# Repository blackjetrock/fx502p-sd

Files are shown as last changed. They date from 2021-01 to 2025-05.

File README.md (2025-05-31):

# Adapter for FX-502p Calculator Interface

Adapter that allows calculator to access and SD card and GPIOs on an STM32. Allows I2c and thermal printer printouts.



 The sketch accepts commands from the 502p and stores the data
 words on the SD card under a filename specified on the 502p. This
 is a three digit number. When loading back the data words are sent
 as they were received.

 The files are FILEtnnn.DAT

    where nnn is the 3 digit file number
    and t is the type of the file:
         M for memories
         P for programs

 We leave the data line as an open drain
 output, even when we want to use it as an input. This saves the
 cycles needed to call pinMode(). Time is short when processing
 the commands from the 502p so all of the processing is done in
 interrupt routines using nested switch FSMs

 The header has been cut down to the minimum that works (50 words)
 and there's no delay when sending data words to or from the 502p.
 This means loading and saving is faster than using the FA-1

 There is code in this sketch to set and read the time and date. This
 uses a DS3231 RTC attached to the PC7 and PC6 GPIO lines on the gpio
 connector J7. On the module I used, GND and VCC lined up with GND and 3V3 on J7 
 so the code uses the GPIO lines that line up with SDA and SCL and create 
 an I2C bus on those pins.

Commands
========

The FX502P communicates with the gadget using the INV SAVE INV EXE keystroke. This saves the 
current display value to the tape interface. The commands are coded in numbers, so to issue a command 
enter the number on the calculator and then press INV SAVE INV EXE
So, for example, to display the help text page onm the OLED display you need to enter 1.0E40 and then
INV SAVE INV EXE. The help text should then be shown on the OLED display.

1.0 E40

This command displays help text on the OLED screen. Press the decimal point key to move
to the next page of help text.

1.1 E40

Display status page

1.2 E40
Display the graphics page.
Pixels can be set on this page using the graphics commands

1.3 E40
Display memory page.
This page shows memories that have been sent using an INV SAVE EXE in MODE 1

1.4 E40
Display text page. text can be placed on this page with the text commands.

1.5 E40
Display token page
This page display program tokens sent using INV SAVE EXE in MODE 3
Page using the decimal point key.

1.6 E40
This page displays the current date and time. An RTC module must be attached using I2C.

1.70 E40
Turns printing off

1.71 E40
Turns printing on

A.BC E47

This sets the current filename for programs to PABC.DAT. This is needed as even though the file number
is entered on the calculator when savng and loading that number does not go over the interface when loading.

A.BC E48

This set sthe current filename to MABC for memory saving and loading.

A.BCD E49

This sets the filename bank to ABCD. The filename banks are a way to have more than 1000 programs or memories stored on an SD card. 

Real Time Clock Commands
------------------------
This requires a DS3231 I2C real time clock module to hold the time and date. It needs to be attached to the I2C

1.0 E42 : Read date

After this is received, the date can be read using an
 
	 inv LOAD inv EXE
	  or
	 inv LOAD EXE

The date is in either the X register or the F memory
respectively.
	 
2.0 E42 : Read time

After this is received, the time can be read using an
 
	 inv LOAD inv EXE
	  or
	 inv LOAD EXE
	
respectively.

2.yymmdd E42 : Set date

3.hhmmss E42 : Set time

Text Display Commands
---------------------

Put text on the display

1.xxyy E41     
  
  Set cursor to (x,y)
  
2.aabbccdd E41   
  
3.aabbccdd E41   
  
  Print text on printer, aa etc are ascii codes

Graphics Display Commands
-------------------------

Sample Programs
---------------

The directory 

Sample_FX502P_Programs

holds some example programs.

- P998  Draws random dots on the OLED display
- IMAG2680

- P999  Draws a sine wave on the OLED display
IMAG2677

Printer
-------

The gadget can drive a simple thermal printer of the type used for receipt printing. An external PSU is required for printing due to the current requirements of the printer. Check the printer details for the curren tit uses, if it doesn't say, assume a 2A or higher PSU is needed, these printers take a lot of current. 
The attachment is on J3. there's an (unmarked) GND connection which should be attached to the PSU for the printer. The TX line sends data to the printer when enabled in the gadget.
When conneted and enabled, saving a program or memories results in the data being printed out, in ASCII.

This is the printer attached to the gadget. The black lead is GND:
IMAG2673

This is the rear of the printer showing the connections:
IMAG2676

The details of the printer PSU I used. This was just one I had lying about, I made a socket connection for it.
IMAG2674

This is th eprinter I used, with some sample output.
IMAG2675

This is the output when printing programs (ignore the memory line at the top, that is what is printed if INV SAVE INV EXE is used in MODE1):
IMAG2679

And this is the printout of memories:
IMAG2678

#
# Note:
# Although the FX-602P uses a similar command set it doesn't yet work with this adapter. It should be possible to make it work though.
# The FX-702p uses the same command set but operates at 5V so it also doesn't work with this adapter without some form of level shifter.

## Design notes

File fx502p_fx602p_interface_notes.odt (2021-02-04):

Casio fx502p fx602p Interface

The Expansion Port

### Pin functions

Expansion Port Pin | Symbol | Function
1 | CE | Chip enable output, active high
2 | GND | Ground (positive supply voltage rail)
3 | D8 | Data input/output (bi-directional)
4 | CONT | -3V when operational, 0V when stand-by
5 | OP | Selects the Command Register (OP=0) or Data Register (OP=1)
6 | VDD1 | -3V (negative supply voltage rail)
7 | SP | Clock output

Additional commands used by the FX-602P

Code Function Description

001100 Wait This command suspends the data transfer for a while when reading from the tape. The calculator issues it after loading of the file header, then reads a single data bit. The meaning of this value is unknown to me (the interface always returns 1).

110100 Counter This command defines the frequency of the music tone. It expects an 8-bit value (the least significant bit first).

frequency = 32768Hz/value

001110 Play the sound After sending this command, signal of frequency specified by the Counter command appears on the MIC output.

111110 Stop the sound This command terminates generating the music tone.

111100 Close Apart from closing the communication channel, this command has an additional function.After sending it, the calculator can read a single data bit which returns the Cal/Music switch state (Cal=0, Music=1). Otherwise, this switch doesn't seem to influence the function of the controller.

Example of playing music

1. OP=0 111100 ;test the Cal/Music switch

OP=1 1 ;returned value=1,

;means the switch in the "Music" position

2. OP=0 111110 ;stop the sound

3. OP=0 110100 ;preset the counter according to the note pitch

OP=1 01001010 ;value=0x52 (frequency=400Hz)

4. OP=0 001110 ;play the sound

5. delay depending on the tempo

6. goto 1, until all notes played

7. OP=0 000000 ;reset

8. OP=0 111110 ;stop the sound

fx602p power on sequence (gadget)

+++Buffer Count:11

*0 19 (6 bits)

*1 03 (6 bits)

*2 00 (1 bits)

*3 1B (6 bits)

*4 03 (6 bits)

*5 00 (1 bits)

*6 19 (6 bits)

*7 03 (6 bits)

*8 00 (1 bits)

*9 00 (6 bits)

*10 3E (6 bits)

fx602p inv save EXE sequence:

*11 19 (6 bits)

*12 07 (6 bits)

*13 07 (6 bits)

*14 0E (7 bits)

*15 28 (6 bits)

*16 04 (6 bits)

*17 00 (1 bits)

*18 04 (6 bits)

*19 00 (1 bits)

*20 04 (6 bits)

*21 00 (1 bits)

*22 04 (6 bits)

*23 00 (1 bits)

*24 04 (6 bits)

*25 00 (1 bits)

*26 04 (6 bits)

*27 00 (1 bits)

*28 04 (6 bits)

*29 00 (1 bits)

*30 04 (6 bits)

*31 00 (1 bits)

*32 04 (6 bits)

*33 00 (1 bits)

*34 04 (6 bits)

*35 00 (1 bits)

*36 04 (6 bits)

*37 00 (1 bits)

*38 04 (6 bits)

*39 00 (1 bits)

*40 04 (6 bits)

*41 00 (1 bits)

*42 04 (6 bits)

*43 00 (1 bits)

*44 04 (6 bits)

*45 00 (1 bits)

*46 04 (6 bits)

*47 00 (1 bits)

*48 00 (6 bits)

*49 00 (1 bits)

*50 04 (6 bits)

*51 00 (1 bits)

*52 04 (6 bits)

*53 00 (1 bits)

*54 04 (6 bits)

*55 00 (1 bits)

*56 04 (6 bits)

*57 00 (1 bits)

*58 04 (6 bits)

*59 00 (1 bits)

*60 0C (6 bits)

*61 00 (1 bits)

*62 04 (6 bits)

*63 00 (1 bits)

*64 04 (6 bits)

*65 00 (1 bits)

*66 04 (6 bits)

*67 00 (1 bits)

*68 0C (6 bits)

*69 00 (1 bits)

*70 04 (6 bits)

*71 00 (1 bits)

*72 04 (6 bits)

*73 00 (1 bits)

*74 04 (6 bits)

*75 00 (1 bits)

*76 0C (6 bits)

*77 00 (1 bits)

*78 04 (6 bits)

*79 00 (1 bits)

*80 04 (6 bits)

*81 00 (1 bits)

*82 04 (6 bits)

*83 00 (1 bits)

*84 0C (6 bits)

*85 00 (1 bits)

*86 04 (6 bits)

*87 00 (1 bits)

*88 04 (6 bits)

*89 00 (1 bits)

*90 04 (6 bits)

*91 00 (1 bits)

*92 0C (6 bits)

*93 00 (1 bits)

*94 04 (6 bits)

*95 00 (1 bits)

*96 04 (6 bits)

*97 00 (1 bits)

*98 04 (6 bits)

*99 00 (1 bits)

*100 0C (6 bits)

*101 00 (1 bits)

*102 04 (6 bits)

*103 00 (1 bits)

*104 04 (6 bits)

*105 00 (1 bits)

*106 04 (6 bits)

*107 00 (1 bits)

*108 0C (6 bits)

*109 00 (1 bits)

*110 04 (6 bits)

fx502p Gadget Traces

Power On:

First column is packet number

*6358 00 (6 bits) ;

*6359 3E (6 bits) ; Stop command

inv SAVE EXE:

*6364 0C (6 bits)

*6365 00 (1 bits)

*6366 28 (6 bits)

*6367 08 (7 bits)

*6368 08 (7 bits)

*6369 08 (7 bits)

*6370 08 (7 bits)

*6371 08 (7 bits)

08 repeats indefinitely.

FX-502P Opcodes

Modifying a program to try out different invalid codes:

0x3B Displays as F5. xD

0x2B E on load

0x2C Seems to behave like HLT

0x2D E on load

0x2E E on load

0x2F Seems to behave like HLT

0x6A E on load

0x9B inv hyp

0xEA FF-F5-CC (inv hyp ABS) inv hyp sin function

0xEB E on load

0xEC FF-F5-C1 (inv hyp FRAC) inv hyp sin function

0xF5 E on load

0xFB FF-PP NOP

0xFC E on load

0xFD Displays as E3 (+) in mode 2 listing, but when executes shows the step in mode 2 format on LCD then locks up the calculator. Power off is only way to recover.

0xFE Displays as 0C Not sure what it does.

0xFF E on load

You can have multiple programs with the same Pn number. Only the last one seems to be loaded. Also can have different invalid Pn numbers and load doesn’t fail, but code isn’t there.

You can easily renumber programs by altering Pn numbers

Altering the first two bytes of a saved program or data file:

23 01 F0123

23 10 F1023 while loading but won’t load

23 20 F2023

23 30 F3123

23 40 F4023

23 50 E on load

23 60 E on load

23 70 F7023

23 80 F8023

23 90 E on load

23 A0 E on load

23 B0 FP023 (program file)

23 C0 E on load

23 D0 FE023

23 F0 FP023 (Memory load)

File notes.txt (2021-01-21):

Extend inv save setting of file numbers beyond 999.

x.yz E 47    Program file number xyz
x.yz E 48    Data file number xyz

This can be extended to

abcdefxyz E 49 sets extended file number but still puts 3 digit number in data.

Programs can't be chained but the external processor could execute it.

Display can be used to decode memories and programs saved and display them
Use display as a larger screen for results.

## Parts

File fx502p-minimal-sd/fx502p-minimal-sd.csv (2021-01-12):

Id | Designator | Package | Quantity | Designation | Supplier and ref
1 | R22 | R_0805_2012Metric_Pad1.15x1.40mm_HandSolder | 1 | 10k
2 | D1 | D_SOD-323_HandSoldering | 1 | D
3 | J7 | PinHeader_1x10_P2.54mm_Vertical | 1 | Conn_01x10_Female
4 | R11,R10 | R_0805_2012Metric | 2 | 10k
5 | JP4,JP3,JP2,JP1 | SolderJumper-2_P1.3mm_Open_RoundedPad1.0x1.5mm | 4 | Jumper
6 | J6,J3 | PinHeader_1x03_P2.54mm_Vertical | 2 | Conn_01x03_Female
7 | X2 | Crystal_SMD_HC49-SD_HandSoldering | 1 | 8MHz
8 | U3 | SOT-223-3_TabPin2 | 1 | AMS1117-3.3
9 | U1 | LQFP-64_10x10mm_P0.5mm | 1 | STM32F103RGTx
10 | SW2 | SMD_BUTTON | 1 | Switch_SW_SPST
11 | R23 | R_0805_2012Metric_Pad1.15x1.40mm_HandSolder | 1 | 1M
12 | R21,R9,R8 | R_0805_2012Metric | 3 | 4k7
13 | R20,R18 | R_0805_2012Metric | 2 | 20R
14 | R7 | R_0805_2012Metric | 1 | 390R
15 | R6,R5,R4,R3,R2,R1 | R_0805_2012Metric | 6 | R_Small
16 | P1 | expansion_fx502p | 1 | Expansion
17 | J10 | PinHeader_1x04_P2.54mm_Vertical | 1 | Conn_01x04
18 | J9 | PinHeader_1x05_P2.54mm_Vertical | 1 | Conn_01x05
19 | J5,J4 | PinHeader_1x04_P2.54mm_Vertical | 2 | Conn_01x04_Male
20 | J2,J1 | PinHeader_1x02_P2.54mm_Vertical | 2 | Conn_01x02_Male
21 | C36,C35,C34,C33,C32,C31,C30,C29,C28,C27,C26,C25,C19 | C_0805_2012Metric_Pad1.15x1.40mm_HandSolder | 13 | 100nF
22 | C24,C22,C20 | C_0805_2012Metric_Pad1.15x1.40mm_HandSolder | 3 | 1uF
23 | C23,C21 | C_0805_2012Metric_Pad1.15x1.40mm_HandSolder | 2 | 10pF
24 | A1 | SD_Card_Module | 1 | SD_Card_Module_catalex

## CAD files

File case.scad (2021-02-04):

// Case for PCB

case_th = 13/2;
pcb_th = 5;

module PCB()
{
  cube([70.2, 65.5, pcb_th], center = true);
  translate([-65.5/2-15/2+15+20, -70.2/2-2/2+0.1, 0])
    cube([15, 2, pcb_th], center=true);
}


module case()
{
    cube([80, 100, case_th], center=true);
}

module calculator()
{
    cube([76.0, 50.0, 2.0], center=true);
    cube([70.7, 50, 9.5], center=true);
}

module case2 ()
{
difference()
{
  translate([0, 0, 0.5])
  case();
  translate([0,0+7.5, case_th/2-1.6/2+0.1-0.8+(5-1.6)/2])
    PCB();
    translate([0, -50, 9.5/2+5/2-9.5/2-1.6/2])
    calculator();
}
}

difference()
{
case2();
    translate([0, 50,0])
    cube([100,100,100], center=true);
}

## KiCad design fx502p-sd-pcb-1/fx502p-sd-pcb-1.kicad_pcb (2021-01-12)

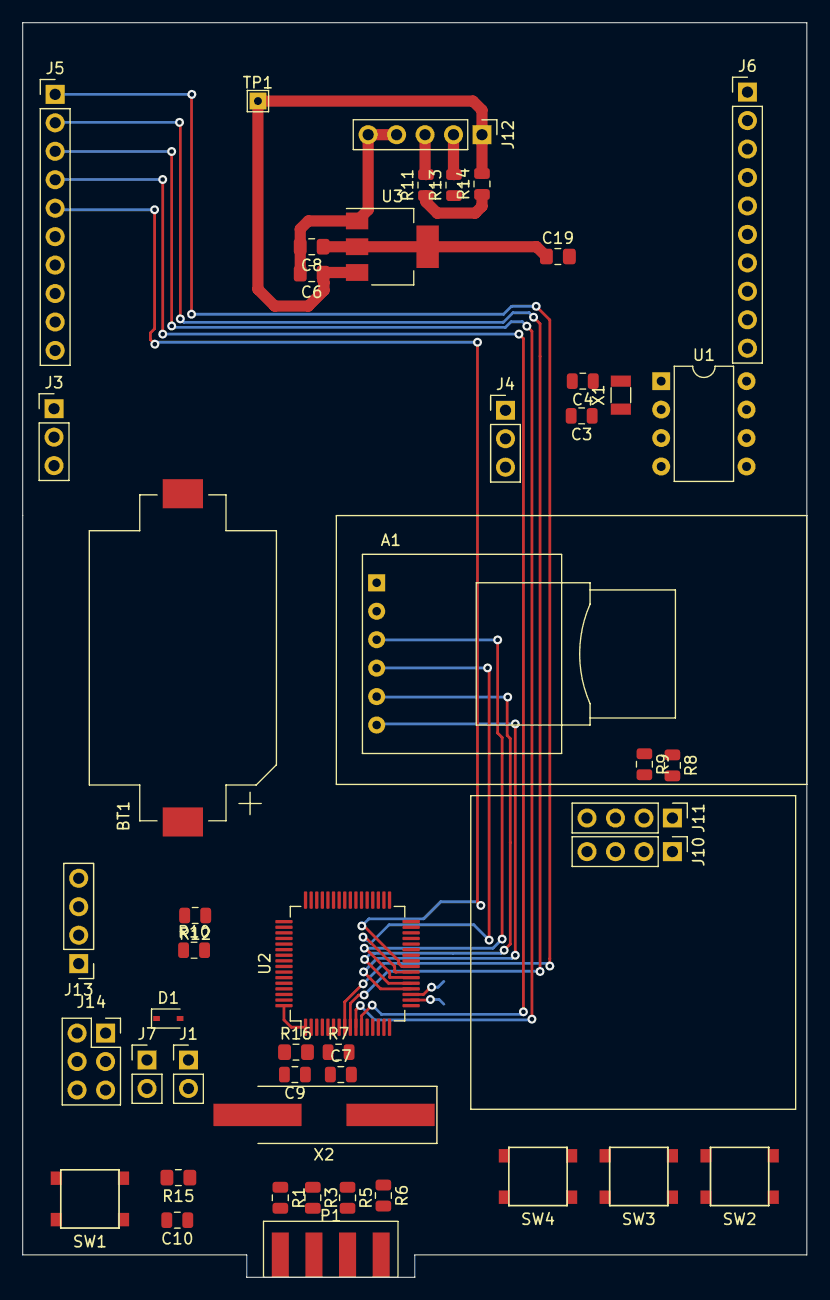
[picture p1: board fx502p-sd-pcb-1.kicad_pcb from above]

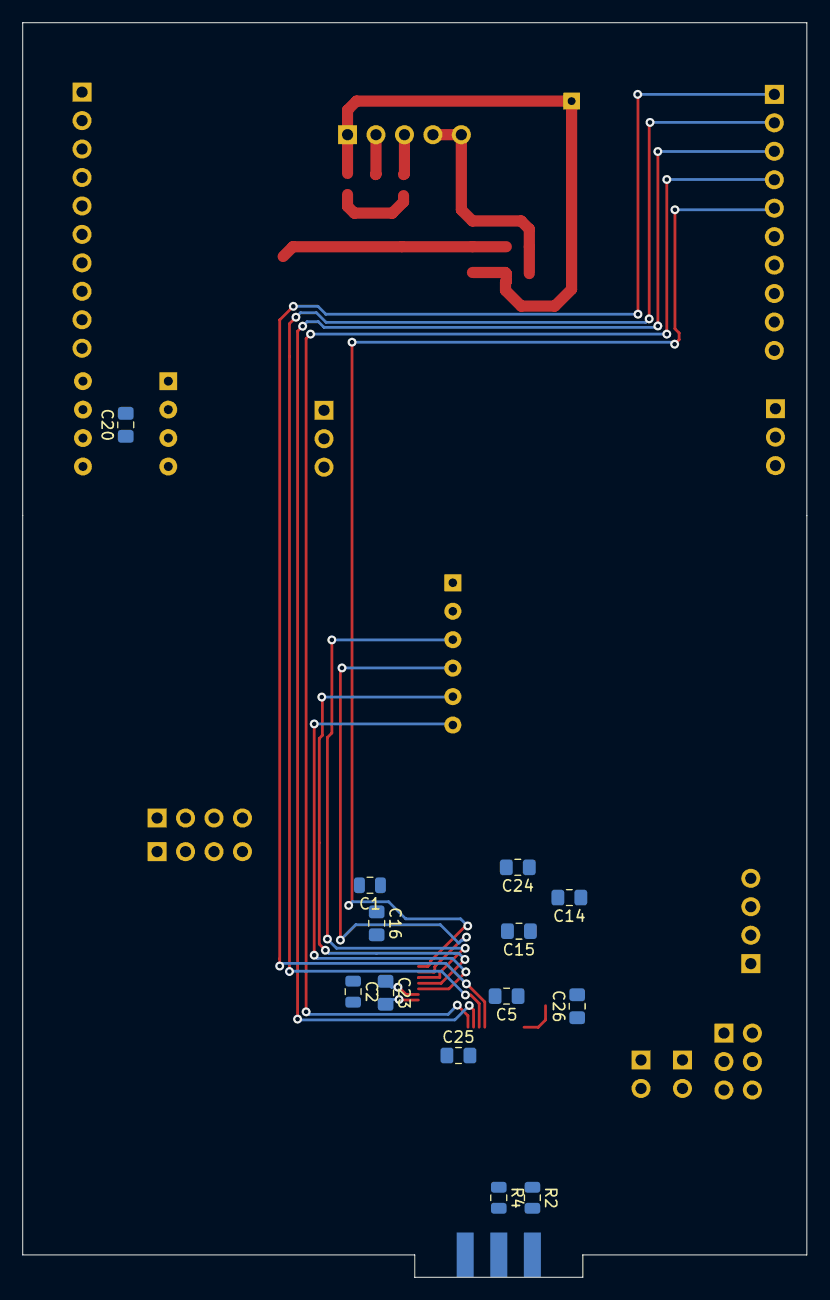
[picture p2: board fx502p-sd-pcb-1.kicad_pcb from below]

Board: 2 copper layers, 70.0 x 112.0 mm, 60 parts (13 on the bottom side), 62 nets.

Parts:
A1: SD_Card_Module_catalex; SD_Card_Module
BT1: Battery_Cell; BatteryHolder_Keystone_1060_1x2032
C1, C2: 100nF; C_0805_2012Metric
C3, C4, C7, C9: 10pF; C_0805_2012Metric
C5, C14, C15, C16, C19, C20, C23, C24, C25, C26: 100nF; C_0805_2012Metric_Pad1.15x1.40mm_HandSolder
C6, C8: 1uF; C_0805_2012Metric_Pad1.15x1.40mm_HandSolder
C10: 1uF; C_0805_2012Metric
D1: D; D_SOD-323
J1, J7: Conn_01x02_Male; PinHeader_1x02_P2.54mm_Vertical
J3: Conn_01x03_Female; PinHeader_1x03_P2.54mm_Vertical
J4: Conn_01x03_Male; PinHeader_1x03_P2.54mm_Vertical
J5, J6: Conn_01x10_Male; PinHeader_1x10_P2.54mm_Vertical
J10, J11: Conn_01x04_Male; PinHeader_1x04_P2.54mm_Vertical
J12: Conn_01x05; PinHeader_1x05_P2.54mm_Vertical
J13: Conn_01x04; PinHeader_1x04_P2.54mm_Vertical
J14: Conn_02x03_Odd_Even; PinSocket_2x03_P2.54mm_Vertical
P1: Expansion; expansion_fx502p
R1, R2, R3, R4, R5, R6, R8, R9: R_Small; R_0805_2012Metric
R7: 390R; R_0805_2012Metric
R10, R12: 10k; R_0805_2012Metric
R11, R13: 20R; R_0805_2012Metric
R14: 4k7; R_0805_2012Metric
R15: 10k; R_0805_2012Metric_Pad1.15x1.40mm_HandSolder
R16: 1M; R_0805_2012Metric_Pad1.15x1.40mm_HandSolder
SW1, SW2, SW3, SW4: Switch_SW_SPST; SMD_BUTTON
TP1: TestPoint; TestPoint_THTPad_1.5x1.5mm_Drill0.7mm
U1: MCP7940N-xSN; DIP-8_W7.62mm
U2: STM32F103RGTx; LQFP-64_10x10mm_P0.5mm
U3: AMS1117-3.3; SOT-223-3_TabPin2
X1: 32.768kHz; Crystal_SMD_3215-2Pin_3.2x1.5mm
X2: 8MHz; Crystal_SMD_HC49-SD_HandSoldering

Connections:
+3V3: C2.1, C5.1, C8.1, C14.1, C15.1, C16.1, C19.1, C20.1, C23.1, C24.1, C25.1, C26.1, J1.1, J4.1, J5.9, J6.9, J10.3, J11.4, J13.1, J14.1, J14.2, R8.1, R9.1, R15.1, U1.8, U2.1, U2.13, U2.19, U2.32, U2.48, U2.64, U3.2
+5V: A1.2, C6.1, J12.1, R14.2, TP1.1, U3.3
BOOT0: R10.2, U2.60
BOOT1: R12.1, U2.28
CALC_CE: R1.1, U2.34
CALC_CONT: R4.1, U2.36
CALC_D3: R3.1, U2.55
CALC_GND: A1.1, BT1.2, C1.2, C2.2, C3.2, C4.2, C5.2, C6.2, C7.2, C8.2, C9.2, C10.2, C14.2, C15.2, C16.2, C19.2, C20.2, C23.2, C24.2, C25.2, C26.2, J3.1, J5.10, J6.10, J10.4, J11.3, J12.4, J12.5, J13.4, J14.5, J14.6, P1.6, SW1.2, SW2.2, SW3.2, SW4.2, U1.4, U2.12, U2.18, U2.31, U2.47, U2.63, U3.1
CALC_OP: R5.1, U2.56
CALC_SP: R6.1, U2.33
CALC_VCC: D1.1, J7.1, U2.35
NRST: C10.1, R15.2, SW1.1, U2.7
unnamed: BT1.1, J4.3
unnamed: C1.1, J4.2, U1.3
unnamed: C3.1, U1.2, X1.2
unnamed: C4.1, U1.1, X1.1
unnamed: D1.2, J1.2
unnamed: J5.1, U2.8
unnamed: J5.2, U2.9
unnamed: J5.3, U2.10
unnamed: J5.4, U2.11
unnamed: J5.5, U2.24
unnamed: J5.6, U2.25
unnamed: J5.7, U2.37
unnamed: J5.8, U2.38
unnamed: J6.1, U2.39
unnamed: J6.2, U2.40
unnamed: J6.3, U2.51
unnamed: J6.4, U2.52
unnamed: J6.5, U2.53
unnamed: J6.6, U2.2
unnamed: J6.7, U2.3
unnamed: J6.8, U2.4
unnamed: J7.2, R2.1
unnamed: J12.2, R13.2
unnamed: J12.3, R11.2
unnamed: J14.3, R10.1
unnamed: J14.4, R12.2
unnamed: P1.1, R1.2
unnamed: P1.2, R2.2
unnamed: P1.3, R3.2
unnamed: P1.4, R4.2
unnamed: P1.5, R5.2
unnamed: P1.7, R6.2
unnamed: R7.2, U2.6
unnamed: SW2.1, U2.14
unnamed: SW3.1, U2.15
unnamed: SW4.1, U2.16
OSCI: C7.1, R16.2, U2.5, X2.1
OSCO: C9.1, R7.1, R16.1, X2.2
PA11: R13.1, U2.44
PA12: R11.1, R14.1, U2.45
RX: J3.2, U2.43
SCL: J10.2, J11.2, R9.2, U1.6, U2.29
SDA: J10.1, J11.1, R8.2, U1.5, U2.30
SD_CLK: A1.5, U2.21
SD_CS: A1.6, U2.20
SD_MISO: A1.3, U2.22
SD_MOSI: A1.4, U2.23
SWDCLK: J13.3, U2.49
SWDIO: J13.2, U2.46
TX: J3.3, U2.42

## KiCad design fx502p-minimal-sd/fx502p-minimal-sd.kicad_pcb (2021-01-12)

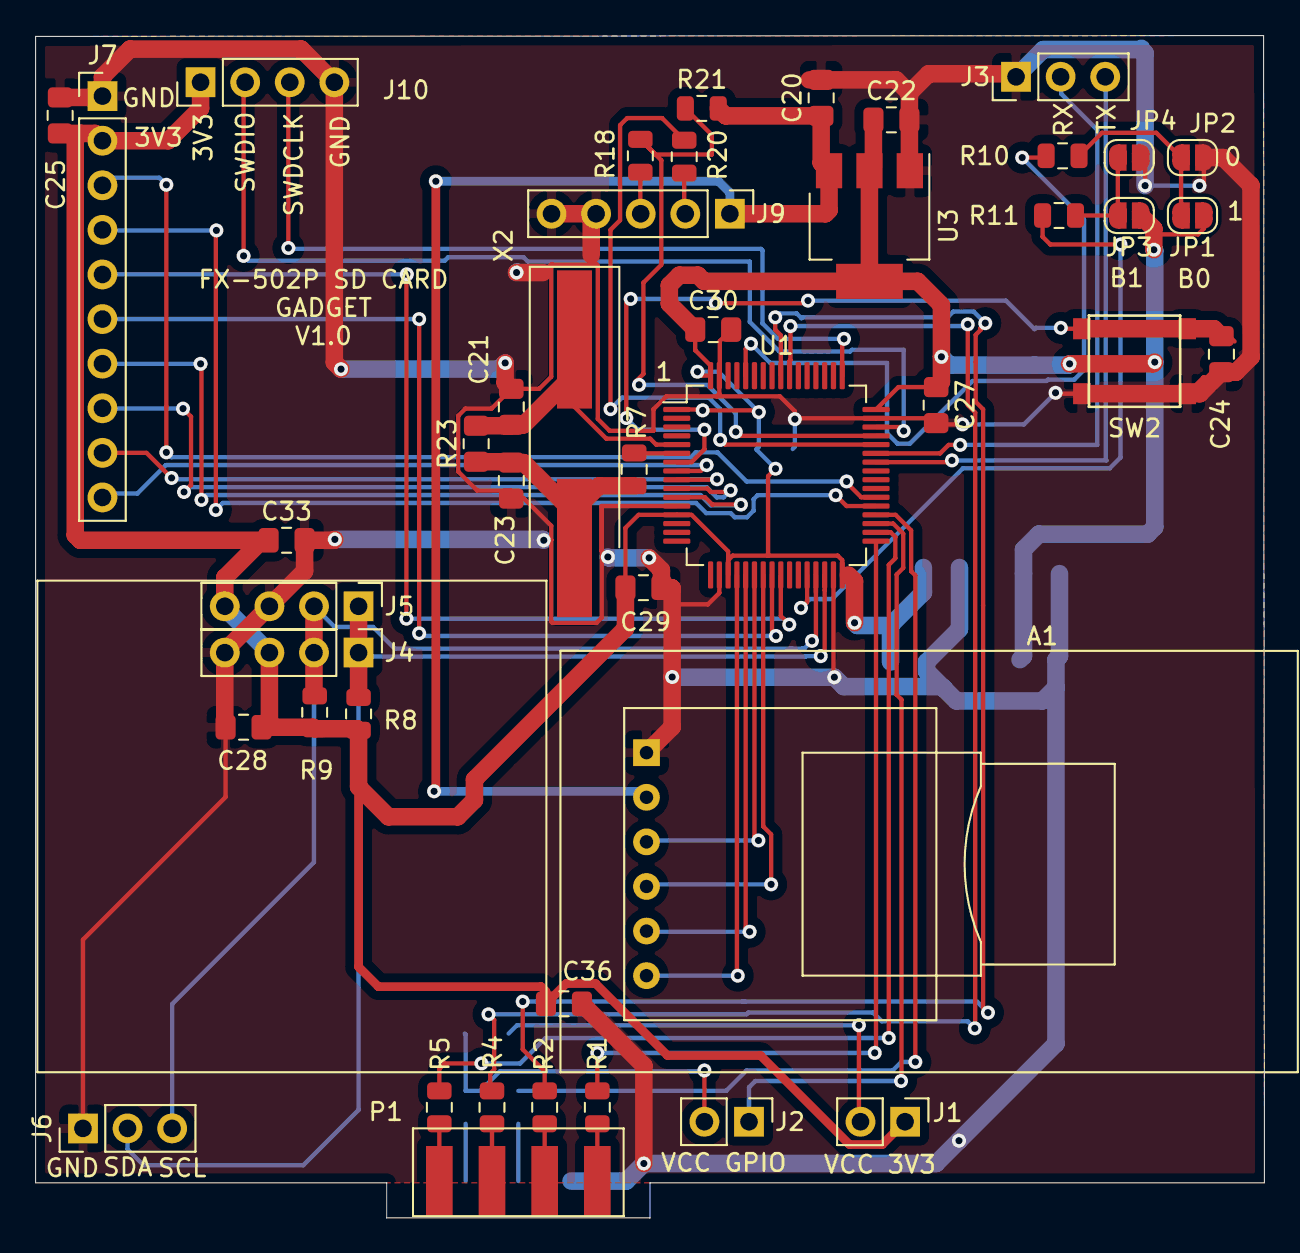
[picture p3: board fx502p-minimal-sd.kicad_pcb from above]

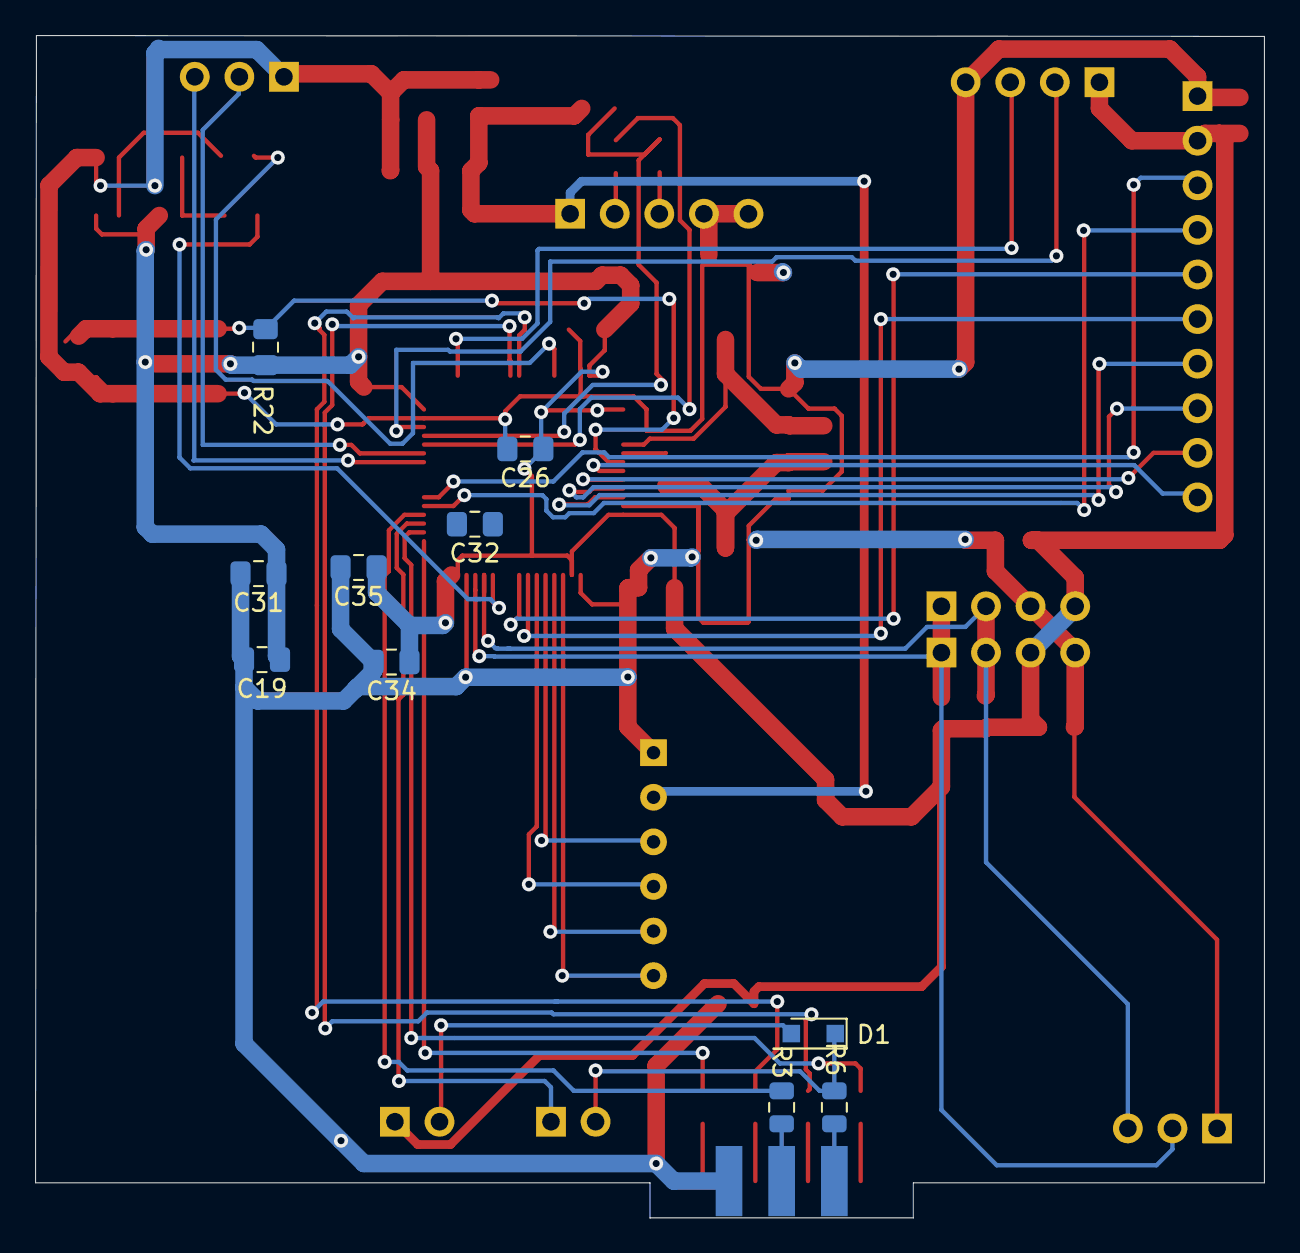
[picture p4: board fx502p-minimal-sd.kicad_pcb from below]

Board: 2 copper layers, 70.0 x 67.3 mm, 54 parts (10 on the bottom side), 47 nets.

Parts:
A1: SD_Card_Module_catalex; SD_Card_Module
C19, C25, C26, C27, C28, C29, C30, C31, C32, C33, C34, C35, C36: 100nF; C_0805_2012Metric_Pad1.15x1.40mm_HandSolder
C20, C22, C24: 1uF; C_0805_2012Metric_Pad1.15x1.40mm_HandSolder
C21, C23: 10pF; C_0805_2012Metric_Pad1.15x1.40mm_HandSolder
D1: D; D_SOD-323_HandSoldering
J1, J2: Conn_01x02_Male; PinHeader_1x02_P2.54mm_Vertical
J3, J6: Conn_01x03_Female; PinHeader_1x03_P2.54mm_Vertical
J4, J5: Conn_01x04_Male; PinHeader_1x04_P2.54mm_Vertical
J7: Conn_01x10_Female; PinHeader_1x10_P2.54mm_Vertical
J9: Conn_01x05; PinHeader_1x05_P2.54mm_Vertical
J10: Conn_01x04; PinHeader_1x04_P2.54mm_Vertical
JP1, JP2, JP3, JP4: Jumper; SolderJumper-2_P1.3mm_Open_RoundedPad1.0x1.5mm
P1: Expansion; expansion_fx502p
R1, R2, R3, R4, R5, R6: R_Small; R_0805_2012Metric
R7: 390R; R_0805_2012Metric
R8, R9, R21: 4k7; R_0805_2012Metric
R10, R11: 10k; R_0805_2012Metric
R18, R20: 20R; R_0805_2012Metric
R22: 10k; R_0805_2012Metric_Pad1.15x1.40mm_HandSolder
R23: 1M; R_0805_2012Metric_Pad1.15x1.40mm_HandSolder
SW2: Switch_SW_SPST; SMD_BUTTON
U1: STM32F103RGTx; LQFP-64_10x10mm_P0.5mm
U3: AMS1117-3.3; SOT-223-3_TabPin2
X2: 8MHz; Crystal_SMD_HC49-SD_HandSoldering

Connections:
+3V3: C19.1, C22.1, C25.1, C26.1, C27.1, C28.1, C29.1, C30.1, C31.1, C33.1, C34.1, C35.1, C36.1, J1.1, J4.3, J5.4, J7.2, J10.1, JP1.1, JP3.1, R8.1, R9.1, R22.1, U1.1, U1.13, U1.19, U1.32, U1.48, U1.64, U3.2
+5V: A1.2, C20.1, J9.1, R21.2, U3.3
BOOT0: R10.1, U1.60
BOOT1: R11.1, U1.28
CALC_CE: R5.1, U1.34
CALC_CONT: R3.1, U1.36
CALC_D3: R4.1, U1.55
CALC_GND: A1.1, C19.2, C20.2, C21.2, C22.2, C23.2, C24.2, C25.2, C26.2, C27.2, C28.2, C29.2, C30.2, C31.2, C33.2, C34.2, C35.2, C36.2, J3.1, J4.4, J5.3, J6.1, J7.1, J9.4, J9.5, J10.4, JP2.1, JP4.1, P1.6, SW2.2, U1.12, U1.18, U1.31, U1.47, U1.63, U3.1
CALC_OP: R2.1, U1.56
CALC_SP: R1.1, U1.33
CALC_VCC_GPIO: J2.1, U1.35
NRST: C24.1, R22.2, SW2.1, U1.7
unnamed: D1.1, J2.2, R6.1
unnamed: D1.2, J1.2
unnamed: J7.3, U1.38
unnamed: J7.4, U1.37
unnamed: J7.5, U1.25
unnamed: J7.6, U1.24
unnamed: J7.7, U1.11
unnamed: J7.8, U1.10
unnamed: J7.9, U1.9
unnamed: J7.10, U1.8
unnamed: J9.2, R20.2
unnamed: J9.3, R18.2
unnamed: JP1.2, JP2.2, R10.2
unnamed: JP3.2, JP4.2, R11.2
unnamed: P1.1, R5.2
unnamed: P1.2, R6.2
unnamed: P1.3, R4.2
unnamed: P1.4, R3.2
unnamed: P1.5, R2.2
unnamed: P1.7, R1.2
unnamed: R7.2, U1.6
OSCI: C21.1, R23.2, U1.5, X2.1
OSCO: C23.1, R7.1, R23.1, X2.2
PA11: R20.1, U1.44
PA12: R18.1, R21.1, U1.45
RX: J3.2, U1.43
SCL: J4.2, J5.2, J6.3, R9.2, U1.29
SDA: J4.1, J5.1, J6.2, R8.2, U1.30
SD_CLK: A1.5, U1.21
SD_CS: A1.6, U1.20
SD_MISO: A1.3, U1.22
SD_MOSI: A1.4, U1.23
SWDCLK: J10.3, U1.49
SWDIO: J10.2, U1.46
TX: J3.3, U1.42

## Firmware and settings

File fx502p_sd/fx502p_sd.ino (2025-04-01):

//
// Sketch to attach to fx502p and read/write data to/from SD card
//
// This sketch accepts commands from the 502p and stores the data
// words on the SD card under a filename specified on the 502p. This
// is a three digit number. When loading back the data words are sent
// as they were received.
//
// The files are FILEtnnn.DAT
//
//    where nnn is the 3 digit file number
//    and t is the type of the file:
//         M for memories
//         P for programs
//
// We leave the data line as an open drain
// output, even when we want to use it as an input. This saves the
// cycles needed to call pinMode(). Time is short when processing
// the commands from the 502p so all of the processing is done in
// interrupt routines using nested switch FSMs
//
// The header has been cut down to the minimum that works (50 words)
// and there's no delay when sending data words to or from the 502p.
// This means loading and saving is faster than using the FA-1
//
// There is code in this sketch to set and read the time and date. This
// uses a DS3231 RTC attached to the PC7 and PC6 GPIO lines on the gpio
// connector J7. 

#include <SPI.h>
#include <SD.h>
#include <Wire.h>
#include <SoftWire.h>
#include <Adafruit_GFX.h>
#include <Adafruit_SSD1306.h>
#include <SoftwareSerial.h>
#if 0
#include "../fx502p_prog_engine/fx502p_prog.h"
#include "../fx502p_prog_engine/fx502p_prog.c"
#endif

// Code configuration
#define USE_HINT_LENGTH            0   // Sometimes we know how long the next packet is
#define LATER_OP_RD                1   // Fixes the problem where the OP GPIO state isn't read correctly,
                                       // so adds a delay before we read it.
#define ENABLE_SERIAL              0
#define ENABLE_OLED_SETUP          1
#define DEBUG_SERIAL               0
#define DIRECT_WRITE               0
#define DROP_ZERO_BIT_PACKETS      1
#define TRACE_CLOCKS               1    // If code > 58K-ish and trace clocks off then
                                        // save load doesn't work. No idea why
                                        // If code size is <58K -ish then tracing clocks stops
                                        // save/load working.
#define TRACE_TAGS                 1
#define DISABLE_MONITOR_DURING_RX  1
#define STAT_OP                    0
#define STAT_CE                    1
#define STAT_SP                    1
#define STAT_BITS_0                0
#define SHIFT_TX_DATA              1
#define TX_CHANGE_RISING_EDGE      1   // TX data changes on rising edge of SP
#define DISPLAY_OTHER_WORDS        0   // Do we display words on th einterface where CE inactive?

#define HEADER_LENGTH            -50
#define HEADER_WORD              0xffff
#define MEMORY_LENGTH             8    // Number of bytes a memory uses
#define NUM_MEMORIES             22

#define SCREEN_WIDTH 128 // OLED display width, in pixels
#define SCREEN_HEIGHT 64 // OLED display height, in pixels


typedef void (*FPTR)();
typedef void (*CMD_FPTR)(String cmd);

// Declaration for an SSD1306 display connected to I2C (SDA, SCL pins)
#define OLED_RESET     4 // Reset pin # (or -1 if sharing Arduino reset pin)

//TwoWire Wire2(PB11,PB10);
Adafruit_SSD1306 display(SCREEN_WIDTH, SCREEN_HEIGHT, &Wire, OLED_RESET);

// Software serial d=for RX/TX header
SoftwareSerial serial_hdr(PA10, PA9); // RX, TX

// Software I2C for the GPIO connector

uint8_t sdaPin = PC_7;
uint8_t sclPin = PC_6;

SoftWire sw(PC_7, PC_6);
char swTxBuffer[16];
char swRxBuffer[16];

AsyncDelay readInterval;

// Clock variables

int clock_day = 0;
int clock_month = 0;
int clock_year = 0;
int clock_hour = 0;
int clock_minute = 0;
int clock_second = 0;

// Macro to set up the first data bit (has to be done on previous clock edge
// before sending the data

#if TX_CHANGE_RISING_EDGE
#define SET_DATA_BIT0  if( (isr_send_data & 1) ) digitalWrite(D3Pin, LOW)
#else
#define SET_DATA_BIT0  ;
#endif

// set up variables using the SD utility library functions:
Sd2Card card;
SdVolume volume;
SdFile root;

int filename_index = 0;

const int chipSelect = PA4;

// Pins for fx502p interface
const int D3Pin      = PB3;
const int OPPin      = PB4;

const int SPPin      = PB12;
const int CEPin      = PB13;
const int VCCPin     = PB14;
const int CONTPin    = PB15;

const int LEDPin     = PC_3;

#define ISOLATE_BIT(N,X) ((X & (1<< N)) >> N)

// Debug outputs
const int statPin   = PC_0;
const int dataPin   = PC_1;


// FSM output flags
boolean cis_flag_event_dotkey = false;
boolean cis_flag_event_ackey = false;
boolean cis_flag_event = false;
char *cis_event = "None";

// Key handlers

void dotkey_null()
{
}

void ackey_null()
{
}

FPTR dotkey_handler = dotkey_null;
FPTR ackey_handler  = ackey_null;

// Event flags
boolean cis_flag_event_read_file = false;  // File data has been read

// File number of data file
char filenum[4] = "...";
char filetype = 'X';

int loopcnt = 0;
volatile int captured_word = 0;
volatile int other_word = 0;
volatile int other_word_bits = 0;
volatile boolean other_word_flag = false;

File myFile;

// Capture file
File dumpfile;


enum
  {
    CIS_IDLE          = 0,
    CIS_502_PO_1      = 1,
    CIS_RX_UNKNOWN_A  = 2,
    CIS_RX_WAIT       = 3,
    CIS_WAIT_2        = 4,
    CIS_WAIT_3        = 5,
    CIS_WAIT_TRANS    = 6,
    CIS_WAIT_DATA     = 7,
    CIS_RD_1          = 8,
    CIS_RD_STAT       = 9,
    CIS_RD_WAIT_TRANS = 10,
    CIS_RD_SENDING    = 11,
    CIS_POSSIBLE_DOT  = 12,
    CIS_POSSIBLE_AC   = 13,    
  };

char *state_decode_list[] =
  {
    "CIS_IDLE",
    "CIS_502_PO_1",
    "CIS_RX_UNKNOWN_A",
    "CIS_RX_WAIT",
    "CIS_WAIT_2",
    "CIS_WAIT_3",
    "CIS_WAIT_TRANS",
    "CIS_WAIT_DATA",
    "CIS_RD_1",
    "CIS_RD_STAT",
    "CIS_RD_WAIT_TRANS",
    "CIS_RD_SENDING",
    "CIS_POSSIBLE_DOT",
    "CIS_POSSIBLE_AC",
  };
  
// Commands
enum
  {
    // Data words
    IP_RESET        = 0x00,
    IP_TRANSFER     = 0x02,
    IP_PRESENCE     = 0x03,
    IP_READ_STATUS  = 0x04,
    IP_WAIT         = 0x0c,
    IP_PLAY         = 0x0e,
    IP_PRTSTR       = 0x10,
    IP_PRTNUM       = 0x11,
    IP_SENDDAT      = 0x13,
    IP_OPEN_RD      = 0x18,
    IP_UNKA         = 0x19,
    IP_TERMINATE    = 0x1f,
    IP_RDSTAT       = 0x21,
    IP_CARRIER_DET  = 0x24,
    IP_OPEN_WR      = 0x28,
    IP_SELPRT       = 0x29,
    IP_SENDCTRL     = 0x33,
    IP_COUNTER      = 0x34,
    IP_CLOSE        = 0x3C,
    IP_STOP         = 0x3E,

    // Special stimulii
    //.    IP_SEND_DONE2   = 0x205D,
    //IP_SEND_DONE    = 0x40BA,
  };

//--------------------------------------------------------------------------------
//
// Memory offsets into the data_words array

#define MEM_OFF_M0F   2
#define MEM_OFF_M09   (MEM_OFF_M0F+MEMORY_LENGTH)
#define MEM_OFF_M08   (MEM_OFF_M09+MEMORY_LENGTH)
#define MEM_OFF_M07   (MEM_OFF_M09+MEMORY_LENGTH)
#define MEM_OFF_M06   (MEM_OFF_M07+MEMORY_LENGTH)
#define MEM_OFF_M05   (MEM_OFF_M06+MEMORY_LENGTH)
#define MEM_OFF_M04   (MEM_OFF_M05+MEMORY_LENGTH)
#define MEM_OFF_M03   (MEM_OFF_M04+MEMORY_LENGTH)
#define MEM_OFF_M02   (MEM_OFF_M03+MEMORY_LENGTH)
#define MEM_OFF_M01   (MEM_OFF_M02+MEMORY_LENGTH)
#define MEM_OFF_M00   (MEM_OFF_M01+MEMORY_LENGTH)

// Offset into a memory where the exponent byte is located
// Offsets are into a stringified memory value
#define MEM_OFF_EXPONENT  15
#define MEM_OFF_D0        1
#define MEM_OFF_D1        3
#define MEM_OFF_D2        4
#define MEM_OFF_D3        5
#define MEM_OFF_D4        6
#define MEM_OFF_D5        7
#define MEM_OFF_D6        8
#define MEM_OFF_D7        9
#define MEM_OFF_D8        10
#define MEM_OFF_D9        11
#define MEM_OFF_D10       12

//--------------------------------------------------------------------------------
//
// FX-502P Program Tokens
//

#define TF_NEWLINE 1      // Newline before token
#define TF_NOGAP   2      // No gaps between nogap tokens
struct
{
  char    *keyword;
  uint8_t flags;
} token_table[256] =
  {
    {"P0", TF_NEWLINE},       
    {"P1", TF_NEWLINE},
    {"P2", TF_NEWLINE},
    {"P3", TF_NEWLINE},
    {"P4", TF_NEWLINE},
    {"P5", TF_NEWLINE},
    {"P6", TF_NEWLINE},
    {"P7", TF_NEWLINE},
    {"P8", TF_NEWLINE},
    {"P9", TF_NEWLINE},
    {"0", TF_NOGAP},
    {"1", TF_NOGAP},
    {"2", TF_NOGAP},
    {"3", TF_NOGAP},
    {".", TF_NOGAP},
    {"EXP", 0x00},
    {"RND0", 0x00},
    {"RND1", 0x00},
    {"RND2", 0x00},
    {"RND3", 0x00},
    {"RND4", 0x00},
    {"RND5", 0x00},
    {"RND6", 0x00},
    {"RND7", 0x00},
    {"RND8", 0x00},
    {"RND9", 0x00},
    {"4", TF_NOGAP},
    {"5", TF_NOGAP},
    {"6", TF_NOGAP},
    {"7", TF_NOGAP},
    {"8", TF_NOGAP},
    {"9", TF_NOGAP},
    {"LBL0", 0x00},
    {"LBL1", 0x00},
    {"LBL2", 0x00},
    {"LBL3", 0x00},
    {"LBL4", 0x00},
    {"LBL5", 0x00},
    {"LBL6", 0x00},
    {"LBL7", 0x00},
    {"LBL8", 0x00},
    {"LBL9", 0x00},
    {"HLT", 0x00},
    {"\"", 0x00},
    {"20+", 0x00},
    {"40+", 0x00},
    {"60+", 0x00},
    {"?2F", 0x00},
    {"GOTO0", 0x00},
    {"GOTO1", 0x00},
    {"GOTO2", 0x00},
    {"GOTO3", 0x00},
    {"GOTO4", 0x00},
    {"GOTO5", 0x00},
    {"GOTO6", 0x00},
    {"GOTO7", 0x00},
    {"GOTO8", 0x00},
    {"GOTO9", 0x00},
    {"xD", 0x00},
    {"?3B", 0x00},
    {"ENG", 0x00},
    {"DMS", 0x00},
    {"LOG", 0x00},
    {"LN", 0x00},
    {"GSBP0", 0x00},
    {"GSBP1", 0x00},
    {"GSBP2", 0x00},
    {"GSBP3", 0x00},
    {"GSBP4", 0x00},
    {"GSBP5", 0x00},
    {"GSBP6", 0x00},
    {"GSBP7", 0x00},
    {"GSBP8", 0x00},
    {"GSBP9", 0x00},
    {"+/-", 0x00},
    {"(", 0x00},
    {")", 0x00},
    {"SIN", 0x00},
    {"COS", 0x00},
    {"TAN", 0x00},
    {"X<>M00", 0x00},
    {"X<>M01", 0x00},
    {"X<>M02", 0x00},
    {"X<>M03", 0x00},
    {"X<>M04", 0x00},
    {"X<>M05", 0x00},
    {"X<>M06", 0x00},
    {"X<>M07", 0x00},
    {"X<>M08", 0x00},
    {"X<>M09", 0x00},
    {"*", 0x00},
    {"/", 0x00},
    {"+", 0x00},
    {"-", 0x00},
    {"=", 0x00},
    {"EXE", 0x00},
    {"Min00", 0x00},
    {"Min01", 0x00},
    {"Min02", 0x00},
    {"Min03", 0x00},
    {"Min04", 0x00},
    {"Min05", 0x00},
    {"Min06", 0x00},
    {"Min07", 0x00},
    {"Min08", 0x00},
    {"Min09", 0x00},
    {"?6A", 0x00},
    {"DSZ", 0x00},
    {"X=0", 0x00},
    {"X=F", 0x00},
    {"RND#", 0x00},
    {"PI", 0x00},
    {"MR00", 0x00},
    {"MR01", 0x00},
    {"MR02", 0x00},
    {"MR03", 0x00},
    {"MR04", 0x00},
    {"MR05", 0x00},
    {"MR06", 0x00},
    {"MR07", 0x00},
    {"MR08", 0x00},
    {"MR09", 0x00},
    {"ISZ",  0x00},
    {"x>=0", 0x00},
    {"x>=F", 0x00},
    {"MEANX", 0x00},
    {"SDX", 0x00},
    {"SDXN", 0x00},
    {"M-00", 0x00},
    {"M-01", 0x00},
    {"M-02", 0x00},
    {"M-03", 0x00},
    {"M-04", 0x00},
    {"M-05", 0x00},
    {"M-06", 0x00},
    {"M-07", 0x00},
    {"M-08", 0x00},
    {"M-09", 0x00},
    {"PAUSE", 0x00},
    {"IND", 0x00},
    {"SAVE", 0x00},
    {"LOAD", 0x00},
    {"MAC", 0x00},
    {"SAC", 0x00},
    {"M+00", 0x00},
    {"M+01", 0x00},
    {"M+02", 0x00},
    {"M+03", 0x00},
    {"M+04", 0x00},
    {"M+05", 0x00},
    {"M+06", 0x00},
    {"M+07", 0x00},
    {"M+08", 0x00},
    {"M+09", 0x00},
    {"XDEL", 0x00},
    {"?9B", 0x00},
    {"SENG", 0x00},
    {"SDMS", 0x00},
    {"10^X", 0x00},
    {"e^X", 0x00},
    {"X<>M10", 0x00},
    {"X<>M11", 0x00},
    {"X<>M12", 0x00},
    {"X<>M13", 0x00},
    {"X<>M14", 0x00},
    {"X<>M15", 0x00},
    {"X<>M16", 0x00},
    {"X<>M17", 0x00},
    {"X<>M18", 0x00},       
    {"X<>M19", 0x00},
    {"ABS", 0x00},
    {"INT", 0x00},
    {"FRAC", 0x00},
    {"ASN", 0x00},
    {"ACS", 0x00},
    {"ATN", 0x00},
    {"Min10", 0x00},
    {"Min11", 0x00},
    {"Min12", 0x00},
    {"Min13", 0x00},
    {"Min14", 0x00},
    {"Min15", 0x00},
    {"Min16", 0x00},
    {"Min17", 0x00},
    {"Min18", 0x00},
    {"Min19", 0x00},
    {"X^Y", 0x00},
    {"X^(1/Y)", 0x00},
    {"R>P", 0x00},
    {"P>R", 0x00},
    {"%", 0x00},
    {"SEXE", 0x00},
    {"MR10", 0x00},
    {"M-11", 0x00},
    {"M-12", 0x00},
    {"M-13", 0x00},
    {"M-14", 0x00},
    {"M-15", 0x00},
    {"M-16", 0x00},
    {"M-17", 0x00},
    {"M-18", 0x00},
    {"M-19", 0x00},
    {"DEG", 0x00},
    {"RAD", 0x00},
    {"GRA", 0x00},
    {"HYPSIN", 0x00},
    {"HYPCOS", 0x00},
    {"HYPTAN", 0x00},
    {"M-10", 0x00},
    {"M-11", 0x00},
    {"M-12", 0x00},
    {"M-13", 0x00},
    {"M-14", 0x00},
    {"M-15", 0x00},
    {"M-16", 0x00},
    {"M-17", 0x00},
    {"M-18", 0x00},
    {"M-19", 0x00},
    {"DEG", 0x00},
    {"RAD", 0x00},
    {"GRA", 0x00},
    {"HYPSIN", 0x00},
    {"HYPCOS", 0x00},
    {"M+10", 0x00},
    {"M+11", 0x00},
    {"M+12", 0x00},
    {"M+13", 0x00},
    {"M+14", 0x00},
    {"M+15", 0x00},
    {"M+16", 0x00},
    {"M+17", 0x00},
    {"M+18", 0x00},
    {"M+19", 0x00},
    {"?EA", 0x00},
    {"?EB", 0x00},
    {"?EC", 0x00},
    {"HYPASN", 0x00},
    {"HYPACS", 0x00},
    {"HYPATN", 0x00},
    {"X<>MF", 0x00},
    {"MinF", 0x00},
    {"MRF", 0x00},
    {"M-F", 0x00},
    {"M+F", 0x00},
    {"?F5", 0x00},
    {"Min1F", 0x00},
    {"MR1F", 0x00},
    {"M-1F", 0x00},
    {"M+1F", 0x00},
    {"AC", 0x00},
    {"?FB", 0x00},
    {"?FC", 0x00},
    {"?FD", 0x00},
    {"?FE", 0x00},
    {"?FF", 0x00},
    
  };


//--------------------------------------------------------------------------------
//
// Preset programs
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
void loop() {
  int i;
  char c;

#if 0
  loopcnt++;
  
  if( (loopcnt % 500000) == 0 )
    {
      //Serial.println("Loop");
    }
#endif
  
#if DISABLE_MONITOR_DURING_RX  
  if( monitor_enabled )
    {
      run_monitor();
    }
#else
  run_monitor();
#endif
  
#if 1
#if DISPLAY_OTHER_WORDS
  if( other_word_flag )
    {
      other_word_flag = false;
      //Serial.print("OW:");
      //Serial.println(other_word);
      
      if( num_other_words < OBUF_LEN )
	{
	  other_data_words[num_other_words++] = other_word;
	}
      
    }
#endif

  if( cis_flag_event_dotkey )
    {
      cis_flag_event_dotkey = false;
      //Serial.println("Dot Key");

      // Call the dot key handler
      (*dotkey_handler)();
    }

  if( cis_flag_event_ackey )
    {
      cis_flag_event_ackey = false;
      //Serial.println("AC Key");

      // Call the AC key handler
      (*ackey_handler)();
    }
  
  if( cis_flag_event )
    {
      cis_flag_event = false;

      
      // Get file number from first two word
      filenum[1] = (unsigned char)(((data_words[0] >> 7) & 0x0F)>>0);
      filenum[2] = (unsigned char)(((data_words[0] >> 7) & 0xF0)>>4);
      filenum[0] = (unsigned char)(((data_words[1] >> 7) & 0xF0)>>4);
      filetype   = (unsigned char)(((data_words[1] >> 7) & 0x0F)>>0);
      filenum[0] = reverse(filenum[0], 4);
      filenum[1] = reverse(filenum[1], 4);
      filenum[2] = reverse(filenum[2], 4);
      filetype   = reverse(filetype, 4);
      filenum[0] += '0';
      filenum[1] += '0';
      filenum[2] += '0';
      filenum[3] = '\0';
      switch(filetype)
	{
	case 11:
	  filetype = 'P';
	  break;
	  
	case 15:
	  filetype = 'M';
	  break;
	}

      if( cis_flag_event_read_file )
	{
	  cis_flag_event_read_file = false;
	  
	  // Write data to a file
	  core_writefile(true);

	  // Check for meta information
	  meta_check();

	  // Print if required
	  do_print();
	}
    }

  if( new_word )
    {
#if 0
      new_word = 0;
      
      Serial.print(copied_word, HEX);
      Serial.print(" ");
      Serial.print(copied_word_bits, HEX);
      Serial.print(" S");
      Serial.println(ce_isr_state);
#endif
#if 0      
      //      display.clearDisplay();
      display.clearDisplay();
      display.setCursor(0,16);
      display.print(captured_word, HEX);
      display.setCursor(0,24);
      display.print(copied_word, HEX);
      display.display();
#endif
    }
#endif
  
#if 0  
  if( Serial2.available(),0 )
    {
      c = Serial2.read();
      //Serial.print(" S");
      //Serial.println(c,HEX);
    }
#endif
  
}

void start_of_packet()
{
  int pb = GPIOB->IDR;
  int op = ISOLATE_BIT(4, pb);

  captured_word = 0;

#if STAT_BITS_0
  digitalWrite(statPin, HIGH);
  digitalWrite(statPin, LOW);
  digitalWrite(statPin, HIGH);
  digitalWrite(statPin, LOW);
#endif
  
  word_bits = 0;
  
  // Record current OP state so we can detect changes
  isr_current_op = op;

  // Not sending data
  //  isr_send_flag = false;
  
#if TRACE_TAGS
  buffer_point(0x1055, 0);
#endif
}

////////////////////////////////////////////////////////////////////////////////
//
//
// Processes the end of a packet. uses an FSM to decide what to do next
//
// This needs to be fast so we don't miss any subsequent interrupts
//
////////////////////////////////////////////////////////////////////////////////

void end_of_packet()
{
#if TRACE_TAGS
  buffer_point(0x10E0, captured_word);
#endif

  // End of packet means data input, so set output HIGH
  // Unless we are sending data
  if( !isr_send_flag )
    {
      digitalWrite(D3Pin, HIGH);
    }
  
#if DROP_ZERO_BIT_PACKETS
  // Ignore zero bit packets
  if( word_bits == 0 )
    {
#if TRACE_TAGS
      buffer_point(0x10E1, 0x1919);
#endif
      return;
    }
#endif
  
  copied_word = captured_word;
  copied_word_bits = word_bits;

  new_word = 1;

  if( isr_send_done )
    {
      buffer_point(isr_send_data_save, word_bits);
    }
  else
    {
      buffer_point(captured_word, word_bits);
    }
  
  // We don't have a lot of time so use a simple
  // nested switch FSM

  switch(ce_isr_state)
    {
    case CIS_IDLE:
      // We aren't transferring a file in either direction
      // so enable the monitor
      monitor_enabled = true;
      
      switch(captured_word)
	{
	  // Close followed by reset is a '.' key
	case IP_CLOSE:
	  ce_isr_state = CIS_POSSIBLE_DOT;
	  break;

	case IP_RESET:
	  ce_isr_state = CIS_POSSIBLE_AC;
	  break;

	case IP_UNKA:
	  ce_isr_state = CIS_RX_UNKNOWN_A;
	  break;

	  // Start of a file being sent from the 502p
	case IP_OPEN_WR:
	  ce_isr_state = CIS_WAIT_2;

	  // Provide the number of bits we are waiting for, as we know what the next
	  // packet will be
	  isr_hint_length = 6;
	  break;

	  // Start of a file being sent to the 502p
	  
	case IP_OPEN_RD:
	  // We start the tx index negative as that indicates header words.
	  // only once the index goes positive (or 0) does the code send
	  // data words form the data words array
	  
	  data_word_tx_index = HEADER_LENGTH;

	  // Provide the number of bits we are waiting for, as we know what the next
	  // packet will be
	  isr_hint_length = 6;
	  
	  ce_isr_state = CIS_RD_1;
	  break;
	  
	case IP_WAIT:
	  // Disable monitor
	  // This is the write path start
	  monitor_enabled = false;
	  
	  ce_isr_state = CIS_RX_WAIT;
	  //	  buf_in = 0;
	  num_data_words = 0;
	  //	  data_word_in_index = 0;
	  
	  // We want to send a 0 bit on the next clock cycle,
	  // set it up
	  isr_send_data = 0;
	  isr_send_data_save = isr_send_data;
	  isr_send_bits = 1;
	  isr_send_bits_save = 1;
	  isr_send_flag = true;
	  SET_DATA_BIT0;
	  break;
	}
      break;

      // We've sent the bit for the WAIT command, wait for it
      // to go and then back to idle
    case CIS_RX_WAIT:
      if( isr_send_done )
	{
	  isr_send_done = false;

	  // We have sent data, now continue
	  captured_word = 0;
	  ce_isr_state = CIS_IDLE;
	  //ce_isr_state = CIS_WAIT_2;
	}
      
      switch(captured_word)
	{

	case IP_STOP:
	  ce_isr_state = CIS_IDLE;
	  break;

	  // This is due to a bad word at start of load path
	case IP_OPEN_RD:
	  // We start the tx index negative as that indicates header words.
	  // only once the index goes positive (or 0) does the code send
	  // data words form the data words array
	  
	  data_word_tx_index = HEADER_LENGTH;
	  
	  ce_isr_state = CIS_RD_1;
	  break;

	}
      break;

      // We've had an open for write, so we go down the write
      // path
    case CIS_WAIT_2:
      switch(captured_word)
	{
	case IP_STOP:
	  ce_isr_state = CIS_IDLE;
	  break;

	case IP_READ_STATUS:
	  // We have the next packet, we need to send a data bit
	  // for this one too
	  isr_send_bits = 1;
	  isr_send_data = 1;
	  isr_send_data_save = isr_send_data;
	  isr_send_bits_save = isr_send_bits;
	  isr_send_flag = true;
	  SET_DATA_BIT0;
	  ce_isr_state = CIS_WAIT_3;
	  break;
#if 1
	case IP_RESET:
	  // End of data, signal event and back to idle
	  if( word_bits == 6 )
	    {
	      cis_flag_event = true;
	      cis_event = "File:";
	      cis_flag_event_read_file = true;
	      
	      ce_isr_state = CIS_IDLE;
	      monitor_enabled = true;
	    }
	  break;
#endif
	}
      
      break;

      // We've had an open for read, so we go down the read
      // path
      
    case CIS_RD_1:
      
      // We disable the monitor here for the read path as it's the first
      // packet received
      monitor_enabled = false;

      switch(captured_word)
	{
	case IP_STOP:
	  ce_isr_state = CIS_IDLE;
	  break;

	case IP_READ_STATUS:
	  // We have the next packet, we need to send a data bit
	  // for this one too
	  isr_send_bits = 1;
	  isr_send_data = 1;
	  isr_send_data_save = isr_send_data;
	  isr_send_bits_save = isr_send_bits;
	  isr_send_flag = true;
	  SET_DATA_BIT0;
	  ce_isr_state = CIS_RD_STAT;
	  break;
#if 1
	case IP_RESET:
	  // End of data, signal event and back to idle
	  if( word_bits == 6 )
	    {
	      cis_flag_event = true;
	      cis_event = "Sent:";
	      
	      ce_isr_state = CIS_IDLE;
	      monitor_enabled = true;
	    }
	  break;
#endif
	}
      
      break;

    case CIS_WAIT_3:
      if( isr_send_done )
	{
	  isr_send_done = false;

	  // Status sent so now we wait for the transfer command
	  captured_word = 0;
#if 0
	  cis_flag_event = true;
	  cis_event = "inv EXE";
#endif
	  ce_isr_state = CIS_WAIT_TRANS;

	}

      switch(captured_word)
	{
	case IP_STOP:
	  ce_isr_state = CIS_IDLE;
	  break;
	}
      break;
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

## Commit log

2020-12-28 Initial check in
    [fx502p_602p_interface_commands.ods]
2020-12-30 Added traces and made sketch changes
2021-01-01 Added traces and sketch now works with internal tracing in buffer
2021-01-02 Latest sketch, not working too well.
    [fx502p_602p_interface_commands.ods]
2021-01-02 Sketch has has pinmode removed. Seems to capture inv save inv exe data. Got display register information from a trace manually.
2021-01-02 Sketch has packet count removed. Manages to count now due to packet_count vs word_length bug.
    [fx502p_sd.ino]
2021-01-02 Captured words decoded to programs
    [prog_dump1.txt]
2021-01-05 Sketch can now pretty reliably receive a file from a 502p. The serial monitor has to be disabled, it appears, as it seems to disable interrupts. That causes errors on the data stream interrupt proces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
    [prog_dump1.txt]
2021-01-06 Sketch now receives and writes files to SD. Sending back is in there, but doesn't work for some reason.
    [prog_dump1.txt]
2021-01-07 Added some files that were written by the gadget after a SAVE on a 502p. Updates to the file decoder and the sketch. Storing data with the SAVE command to SD card works with this version. LOADing bac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
    [fx502p_sd.ino]
2021-01-09 Updates to sketch, and misc other files
    [prog_dump1.txt]
2021-01-12 Created a minimal PCB as a first attempt at PCB sizes etc. If this works then maybe do the full card with lots of IO that I was starting with.
    [VFD.sch, cq1re1.sch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]
2021-01-21 Modified permissions
    [VFD.sch, cq1re1.sch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]
2021-01-27 Modified to run on the larger STM32F103RE (or larger) This is a 64 pin package. The OLED display is on Wire2 so needed an adjustment. All else seems fine and it has run on a 502P
2021-01-27 Added more menu optiosn ot try to get to editing of buffer. Now doesn't work
    [fx502p_sd.ino]
2021-01-27 Turned monitor off during rx. Didn't make this build work again
    [fx502p_sd.ino]
2021-01-28 Adding memory decode and found that when code size increases the interface to the calculator stops working. It looks like CE interrupt is late relative to the clock.
2021-01-29 Fixed save, load still doesn't work. The fix was to add a hint length for the next packet. When that is reached we do an end-of-packet action. This is because the OP ISr seems to be out of sequence (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
    [fx502p_sd.ino]
2021-01-29 the SAVE and LOAD is now working on fx502p using any code size. The problem seems to be that when the OP GPIO line is read it doesn't read the current pin state. reading the GPIO later in the ISR see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
    [fx502p_sd.ino]
2021-01-29 Updates. Added LED toggle on PC3 when fiel written. Crude way for calc to drive GPIO port.
2021-02-02 Added noteson undefined opcodes in programs and a case/ holder for PCB
    [case.scad]
2021-02-04 Added the softwire library so I2C should be accessible on the GPIO port. Doesn't work on DS3231 RTC for some reason.
    [case.scad]
2021-02-04 Added some files
    [mem_dump.txt]
2021-02-06 Added program display. Shows the currently loaded data words as a program in text form. Has word wrap. As it won't all fit on one page, the dot key can be used to page the display.
    Also had a nasty emacs editing problem. Everything seems to be recovered but there could be lingering problems.
    [fx502p_sd.ino]
2021-02-11 Fixed the clock routine that reads an attached I2C RTC DS3231 on test module.
    [fx502p_sd.ino]
2021-02-12 Added time and date commands that access an attached DS3231 on the GPIO lines.
2021-02-14 Updates for temperature/light/pot ADC/DA sensor PCF8951
2021-02-23 Added basic support for a receipt printer attached to expansion GPIO header
2021-02-23 Tidied up printing. Added 1.70e40 and 1.71e40 to turn print flag off and on. Memory print out now stops on invalid entries.
2022-08-22 Removed serial output as it stopped the software serial code from driving the printer once it had initialised (the serial library).
    [fx502p-sd-pcb-1.sch, stm_support.sch]
2022-08-23 Fixed debug code in text screen
    [fx502p_sd.ino]
